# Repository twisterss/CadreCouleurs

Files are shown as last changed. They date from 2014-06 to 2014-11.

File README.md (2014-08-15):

# Decorative LED frame

## More info

Find details about the way to [build the frame yourself here](http://www.viesurip.fr/en/2014/06/17/un-cadre-en-couleurs/).

## Repository structure

  * The "cadre" directory contains the Arduino sketch to control the display;
  * The "elec" directory contains the schematic of the control part of the frame;
  * The "things" directory contains the models to 3D-print or laser-cut to modify the frame;
  * The "tools" directory contains various tools useful to modify the frame.

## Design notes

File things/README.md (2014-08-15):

# 3D parts for the frame

OpenSCAD has been used to build the 3D models.

## The box

It contains the electronics of the frame. It can easily by 3D-printed in two parts.

## The grid

It separates the LEDs. It can be either 3D-printed (STL files) or laser-cut (SVG file produced using Python).

It is better to print it in one part, but it can be printed in two parts.

## The holder

It is used to keep the grid inside the frame.

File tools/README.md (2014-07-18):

# Tools for the frame

* colors.py script to generate a list of colors to load on the Arduino
* Color loader sketch to fill the EEPROM memory with color values
* font spreadsheet to design characters to display on the frame

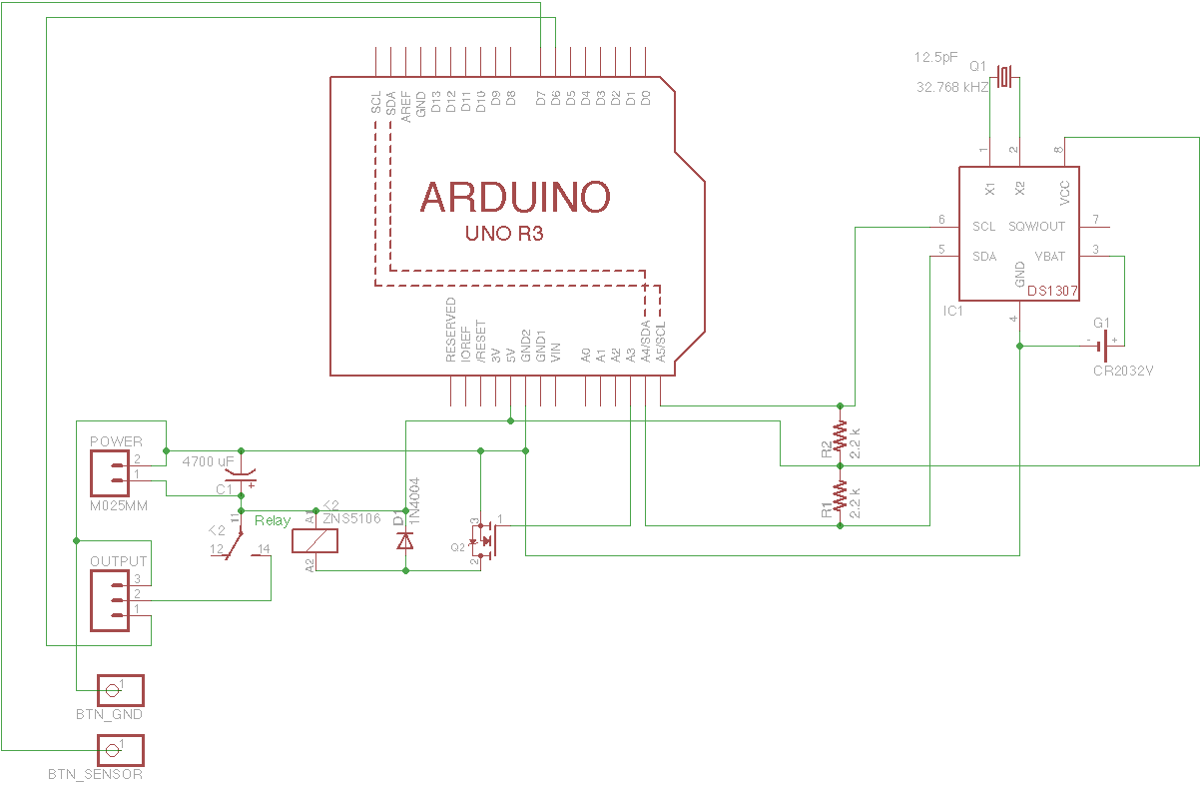
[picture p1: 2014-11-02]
elec/control-circuit.png

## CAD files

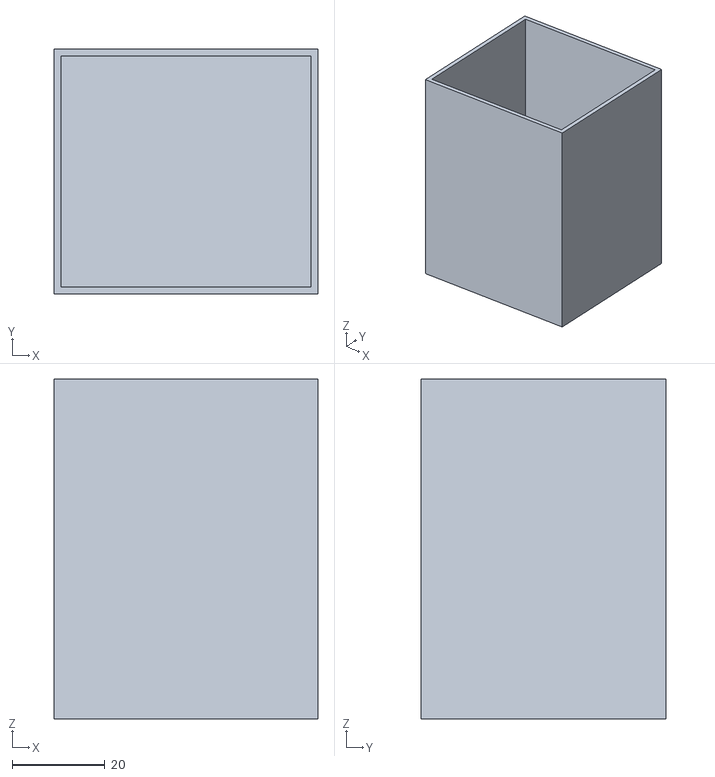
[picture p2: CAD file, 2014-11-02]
things/box_full.stl
57.0 x 53.0 x 73.5

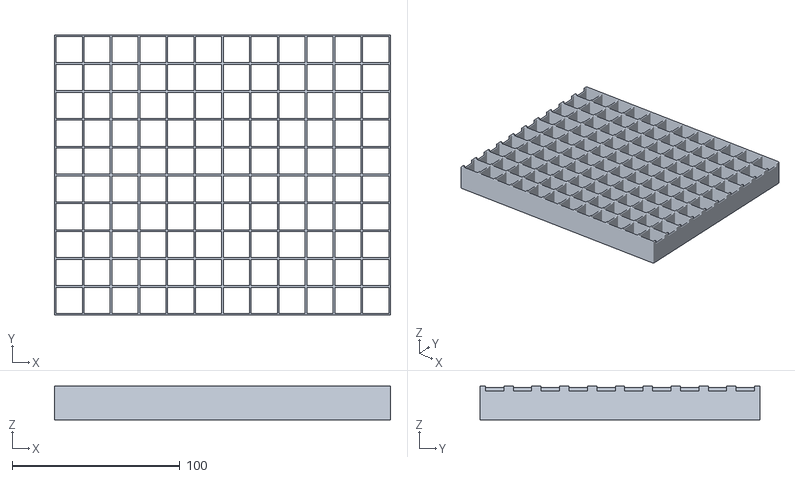
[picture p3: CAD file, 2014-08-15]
things/full_grid.stl
200.2 x 167.0 x 20.0

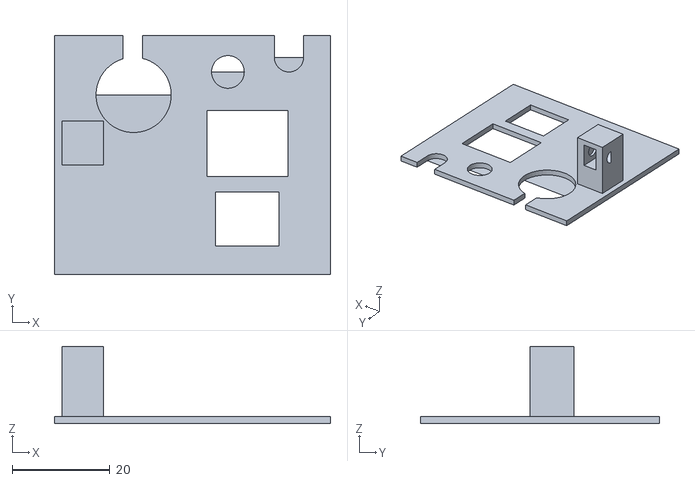
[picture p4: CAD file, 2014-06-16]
things/box_end.stl
56.5 x 49.0 x 15.8

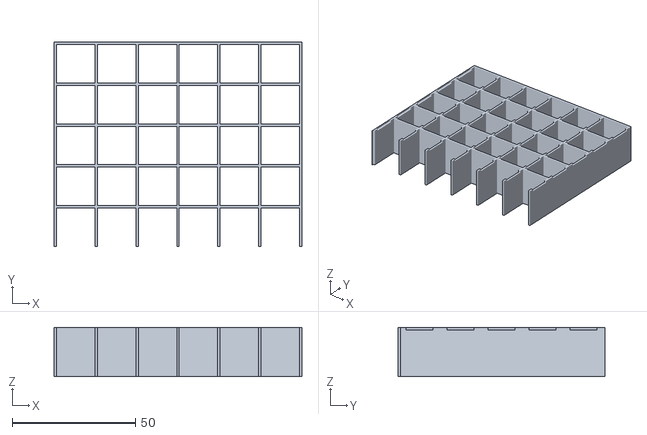
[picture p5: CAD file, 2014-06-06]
things/grid_y.stl
100.6 x 84.0 x 20.0

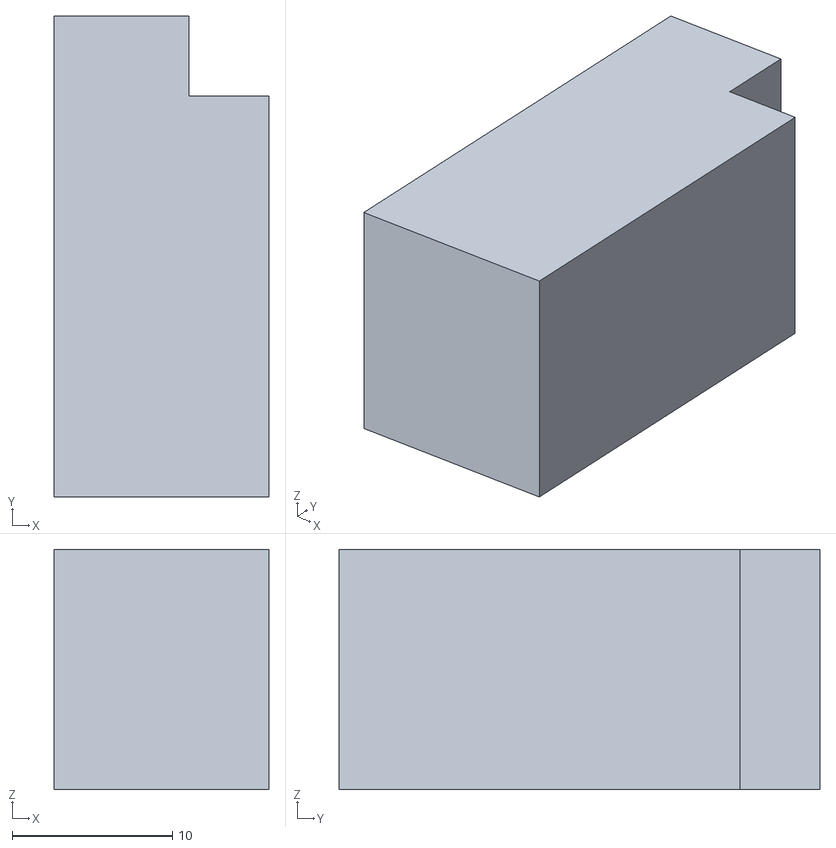
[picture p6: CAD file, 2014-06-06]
things/holder.stl
13.4 x 30.0 x 15.0

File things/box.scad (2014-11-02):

$fn = 50;

content_width = 54;
content_depth = 72;
content_height = 50;
wall = 1.5;
screw_sep = 5;
screw_bottom = 21;
screw_diam = 3.5;
screw_width = 6.3;
screw_height = 7.5;
screw_depth = 4;

module box() {
	difference() {
		cube([content_width + wall*2, content_depth + wall, content_height + wall * 2]);
		translate([wall, wall, wall]) {
			cube([content_width, content_depth, content_height]);
		}
	}
}

module end() {
	translate([0, content_depth + wall, 0]) {
		union() {
			difference() {
				cube([content_width + wall * 2, wall, content_height + wall * 2]);
				translate([wall, 0, wall]) {
					// Power hole
					translate([content_width-10, 0, content_height - 3])
						cube([6, wall, 3 + wall]);
					translate([content_width-7, wall, content_height - 3])
						rotate([90, 0, 0])
							cylinder(h = wall+1, r = 3);
					// USB hole
					translate([31.5, 0, 4.4])
						cube([13, wall, 11]);
					// Ethernet hole
					translate([29.75, 0, 18.6])
						cube([16.5, wall, 13.5]);
					// Output plug hole
					translate([12.5, 0, content_height + wall - 6])
						cube([4, wall, 6]);
					translate([14.7, wall, content_height - 10.7])
						rotate([90, 0, 0])
							cylinder(h = wall+1, r = 7.7);
					// Button hole
					translate([34, wall, content_height - 6])
						rotate([90, 0, 0])
							cylinder(h = wall+1, r = 3.35);
				}
			}
			// Holding part 1
			translate([wall, -(screw_sep + screw_width + wall*2), screw_bottom + wall]) {
				difference() {
					cube([wall*3 + screw_depth, screw_sep + screw_width + wall*2, screw_height + wall]);
					translate([wall*1.5, wall, wall])
						cube([screw_depth, screw_width, screw_height]);
					translate([0, screw_width/2 + wall, screw_height/2 + wall])
						rotate([0, 90, 0])
							cylinder(h = wall*3 + screw_depth, r = screw_diam/2);
				}
			}
		}
	}
}

box();
end();

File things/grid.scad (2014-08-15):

// Grid to separate pixels on the frame.
// Can be 3D-printed in 1 or 4 parts.
// See different combinations at the end of the file

// Basic dimensions
pixel_width = 16.6;
pixel_wall = 1;
pixel_height = 20;
strip_width = 11;
strip_height = 0.8;
strip_big_height = 2.8;

// Grid drawing module
// pixels_x, pixels_y: Grid size
// remove_wall_x, remove_wall_x: Leave space to put another grid side by side
// bigger_strip_start, bigger_strip_end: Leave space for soldering on the end
module grid(pixels_x, pixels_y, remove_wall_x, remove_wall_y, bigger_strip_start, bigger_strip_end) {
	difference() {
		union() {
			for (x = [0 : pixels_x]) {
				translate([x * pixel_width, 0, 0])
					cube([pixel_wall, pixels_y * pixel_width + pixel_wall, pixel_height]);
			}
			for (y = [0 : pixels_y]) {
				translate([0, y * pixel_width, 0])
					cube([pixels_x * pixel_width + pixel_wall, pixel_wall, pixel_height]);
			}
		}
		for (y = [0 : pixels_y-1]) {
			translate([0, (pixel_width + pixel_wall - strip_width)/2 + y * pixel_width, 0]) {
				cube([pixels_x * pixel_width + pixel_wall, strip_width, strip_height]);
				if (bigger_strip_start)
					cube([pixel_wall, strip_width, strip_big_height]);
				if (bigger_strip_end)
					translate([pixels_x * pixel_width, 0, 0])
						cube([pixel_wall, strip_width, strip_big_height]);
			}
		}
		if (remove_wall_x)
			cube([pixel_wall, pixels_y * pixel_width + pixel_wall, pixel_height]);
		if (remove_wall_y)
			cube([pixels_x * pixel_width + pixel_wall, pixel_wall, pixel_height]);
	}
}

// Full grid made of one part
grid(12, 10, 0, 0, 1, 1);

// Grid made of 4 parts for smaller printers (print both twice)
//grid(6, 5, 1, 0, 0, 0);
//translate([6*pixel_width+5, 0, 0])
//	grid(6, 5, 0, 1, 0, 0);

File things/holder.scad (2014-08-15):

// Holder to prevent the grid from moving inside the frame
// For the laser-cut grid, use holder=0

// Actual inside width of the frame
frame_width = 217;

// Size of the grid
pixel_width = 16.6;
pixel_wall = 1;
pixel_height = 20;

pixels_x = 12;
pixels_y = 10;

// Size of the protruding parts holding the grid
holder = 5;

difference() {
	cube([(frame_width - pixel_width * pixels_x - pixel_wall) / 2 + holder, (frame_width - pixel_width * pixels_y - pixel_wall) / 2 + holder, pixel_height-5]);
	translate([(frame_width - pixel_width * pixels_x - pixel_wall) / 2, (frame_width - pixel_width * pixels_y - pixel_wall) / 2, 0])
		cube([holder+1, holder+1, pixel_height-5]);
}

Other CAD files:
things/grid_x.stl

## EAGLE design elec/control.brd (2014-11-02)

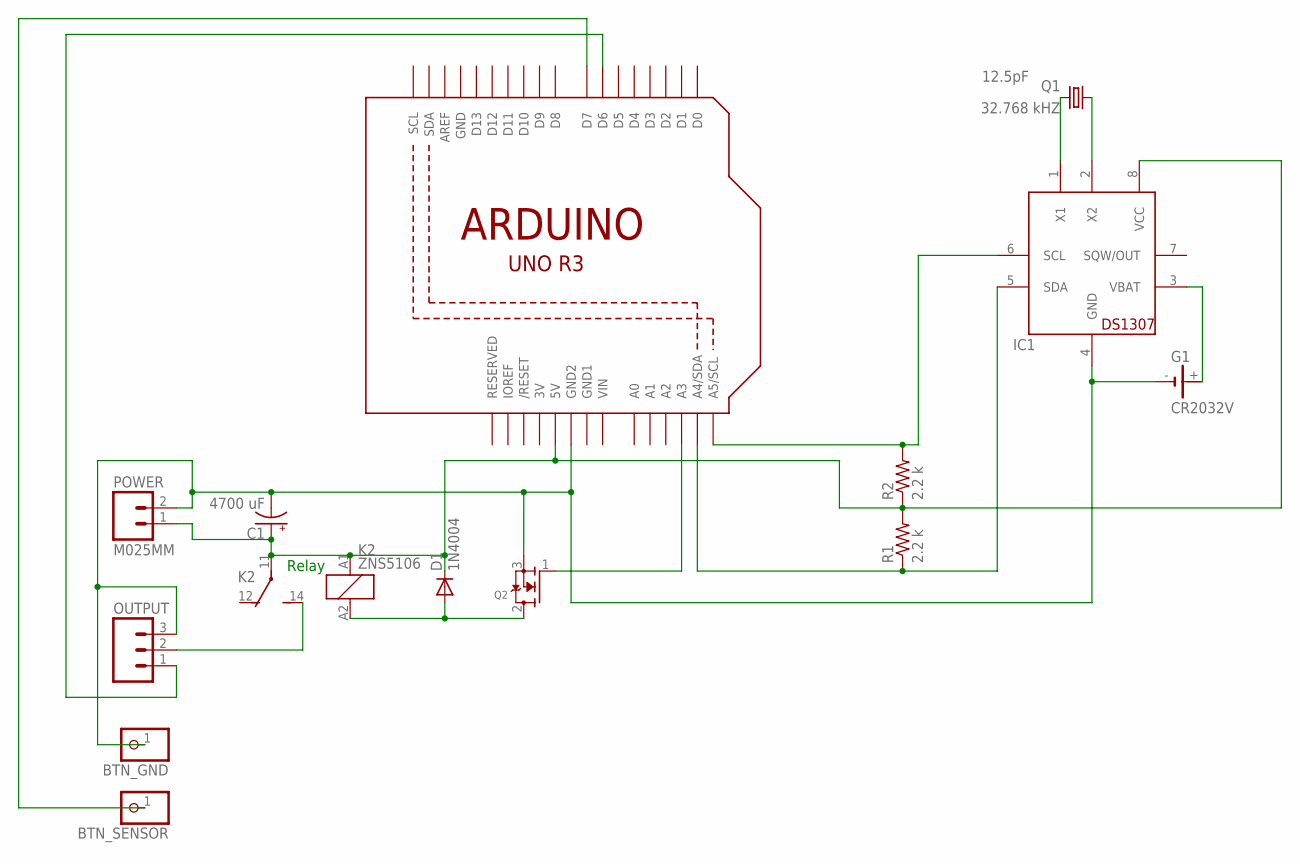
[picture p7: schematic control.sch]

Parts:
BTN_GND: PINHD-1X1CB; 1X01-CLEANBIG
BTN_SENSOR: PINHD-1X1CB; 1X01-CLEANBIG
C1: 4700 uF; E5-10,5
D1: 1N4004; DO41-10
G1: CR2032V
IC1: DS1307; DIL08
K2: ZNS5106; ZN5
OUTPUT: M03-SCREW-5MM; SCREWTERMINAL-5MM-3
POWER: M025MM; SCREWTERMINAL-5MM-2
Q1: 32.768 kHZ; TC38H
Q2: MOSFET-NGDS_TO220V; TO220V
R1, R2: 2.2 k; 0207/10
U1: ARDUINOR3-BPLACE

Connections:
3V: U1.3V
GND: U1.GND
GND1: U1.GND1
unnamed: BTN_GND.1, C1.-, G1.-, IC1.4 (GND), OUTPUT.3, POWER.2, Q2.3 (S), U1.GND2
unnamed: IC1.1 (X1), Q1.2
unnamed: Q2.1 (G), U1.A3
unnamed: D1.A, K2.A2 (2), Q2.2 (D)
unnamed: K2.14 (S), OUTPUT.2
unnamed: OUTPUT.1, U1.D6
unnamed: BTN_SENSOR.1, U1.D7
unnamed: IC1.2 (X2), Q1.1
unnamed: G1.+, IC1.3 (VBAT)
unnamed: IC1.6 (SCL), R2.2, U1.A5 (A5/SCL)
unnamed: IC1.5 (SDA), R1.1, U1.A4 (A4/SDA)
unnamed: C1.+, D1.C, IC1.8 (VCC), K2.11, K2.A1 (1), POWER.1, R1.2, R2.1, U1.5V
VIN: U1.VIN

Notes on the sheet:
Relay

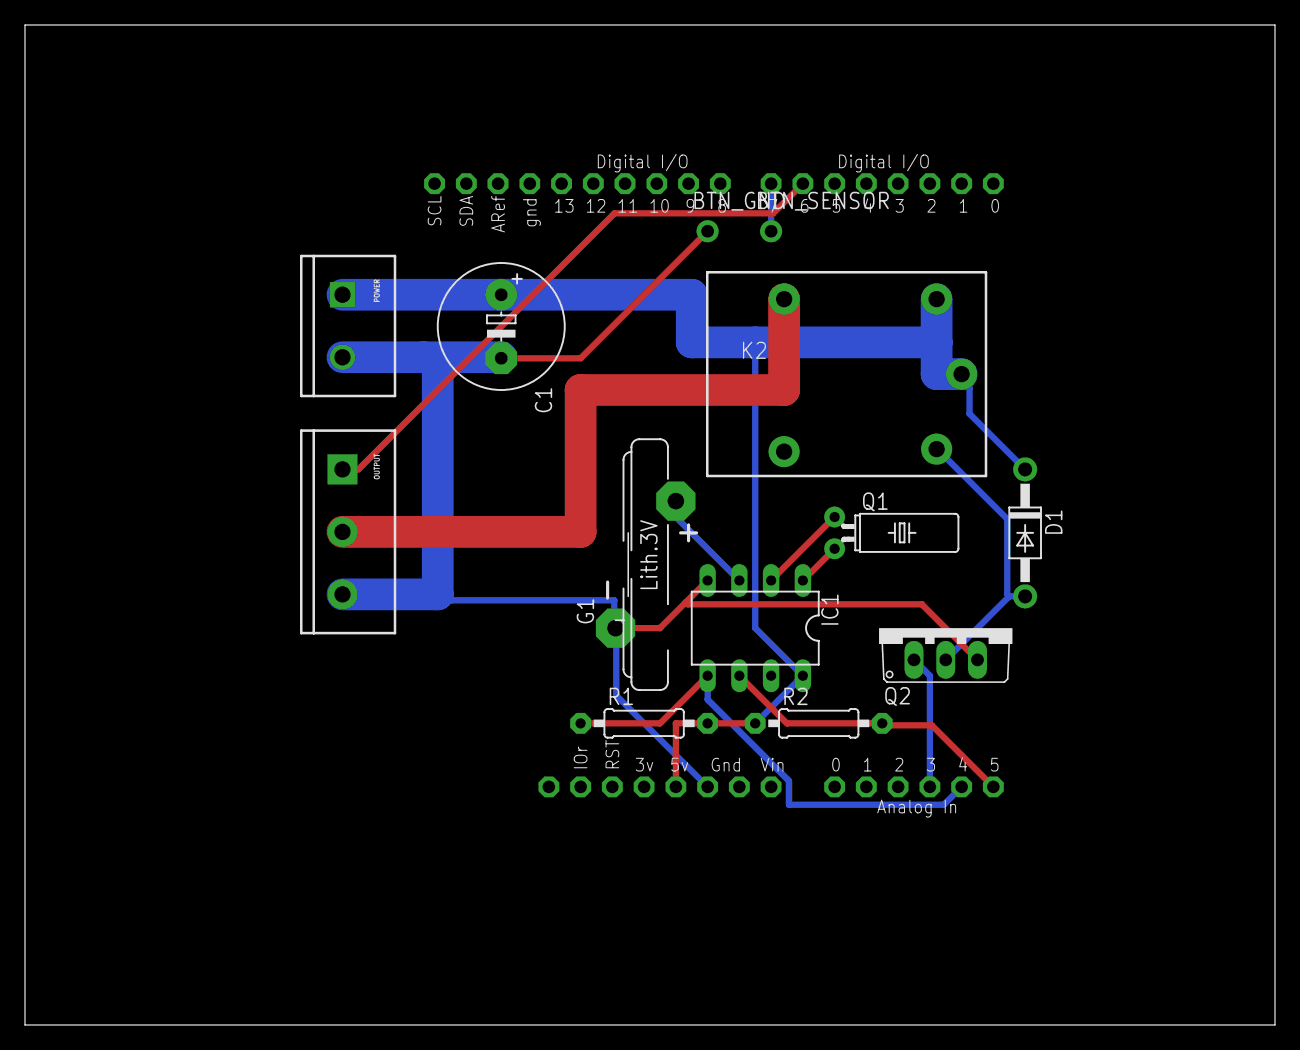
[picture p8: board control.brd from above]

Board: 2 copper layers, 100.0 x 80.0 mm, 14 parts (0 on the bottom side), 12 nets.

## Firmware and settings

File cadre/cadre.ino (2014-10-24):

// This is the main sketch of the color frame.
// It contains a control web server and the display control.
// Think of loading colors in the EEPROM before using this sketch.

#include <avr/wdt.h>
#include <SPI.h>
#include <Ethernet.h>
#include <Wire.h>  
#include "RTCControl.h"
#include <Time.h> 
#include <Adafruit_NeoPixel.h>
#include "Pixels.h"
#include "WebServer.h"
#include <EEPROM.h>

// Hardware configuration
#define STRIP_PIN_DATA 6
#define STRIP_PIN_POWER A3
#define BUTTON_PIN 7

// Minimum delay between two display states (microseconds)
#define DISPLAY_DELAY 1000
// Maximum number of characters for a displayed message
#define MAX_TEXT_SIZE 30

// Number of colors stored in EEPROM
#define COLOR_HUES 85
#define COLOR_SATS 4

// Working modes
#define MODE_OFF 0
#define MODE_CLOCK 1
#define MODE_COLOR 2
#define MODE_GRADIENT 3
#define MODE_RANDOM 4
#define MODE_TEXT 5
#define MODE_DEMO 6
#define MODE_RAINBOW 8
#define MODE_ADDRESS 255

// MAC address of the server
byte mac[] = {
  0x90, 0xA2, 0xDA, 0x00, 0xEA, 0xF8
};

// Letters to display (5x5)
const byte letters[][5] = {
  {0x7c,0x44,0x44,0x7c,0x44}, // A
  {0x7c,0x44,0x78,0x44,0x7c},  
  {0x7c,0x40,0x40,0x40,0x7c},  
  {0x78,0x44,0x44,0x44,0x78},  
  {0x7c,0x40,0x78,0x40,0x7c},
  {0x7c,0x40,0x70,0x40,0x40},
  {0x7c,0x40,0x4c,0x44,0x7c},
  {0x44,0x44,0x7c,0x44,0x44},
  {0x7c,0x10,0x10,0x10,0x7c},
  {0x0c,0x04,0x04,0x44,0x7c},
  {0x44,0x48,0x70,0x48,0x44},
  {0x40,0x40,0x40,0x40,0x7c},
  {0x44,0x6c,0x54,0x44,0x44},
  {0x44,0x64,0x54,0x4c,0x44},
  {0x38,0x44,0x44,0x44,0x38},  
  {0x78,0x44,0x78,0x40,0x40},              
  {0x7c,0x44,0x44,0x7c,0x10},            
  {0x78,0x44,0x78,0x44,0x44},            
  {0x7c,0x40,0x7c,0x04,0x7c},            
  {0x7c,0x10,0x10,0x10,0x10},              
  {0x44,0x44,0x44,0x44,0x7c},            
  {0x44,0x44,0x28,0x28,0x10},            
  {0x44,0x44,0x54,0x54,0x28},            
  {0x44,0x28,0x10,0x28,0x44},            
  {0x44,0x44,0x28,0x10,0x10},            
  {0x7c,0x08,0x10,0x20,0x7c}, // Z
  {0x38,0x4C,0x54,0x64,0x38}, // 0
  {0x70,0x10,0x10,0x10,0x7C},
  {0x7C,0x04,0x7C,0x40,0x7C},
  {0x7C,0x04,0x1C,0x04,0x7C},
  {0x40,0x48,0x7C,0x08,0x08},
  {0x7C,0x40,0x7C,0x04,0x7C},
  {0x7C,0x40,0x7C,0x44,0x7C},
  {0x78,0x08,0x1C,0x08,0x08},
  {0x38,0x44,0x38,0x44,0x38},
  {0x7C,0x44,0x7C,0x04,0x7C}, // 9  
  {0x00,0x00,0x00,0x00,0x00}, // space
  {0x00,0x00,0x00,0x30,0x30}, // dot
  {0x28,0x7C,0x7C,0x38,0x10}, // heart
  {0x00,0x28,0x00,0x44,0x38}, // happy smiley
  {0x00,0x28,0x00,0x38,0x44}  // unhappy smiley
};

// Web server
WebServer server(80);
// LED strip
Pixels pixels(STRIP_PIN_DATA, STRIP_PIN_POWER);

// Display state
unsigned long lastDisplayEvent = 0;
bool newOrderReceived = true;
bool newOrderInternal = false;

// Current configuration (used by all modes)
typedef struct State {
  uint8_t mode;
  uint32_t color1;
  uint32_t color2;
  char text[MAX_TEXT_SIZE];
  uint8_t speed;
  uint8_t brightness;
} State;
State current;

/**
 * Load the current state from RTC RAM
 */
void loadCurrent() {
  RTC.readBytesInRam(0, sizeof(current), (uint8_t*) &current);
}

/**
 * Save the current state in RTC RAM
 */
void saveCurrent() {
  RTC.writeBytesInRam(0, sizeof(current), (uint8_t*) &current);
}

/**
 * Mix 2 colors together.
 * If step = 0, this is color1, if step = maxStep, this is color2, between, this is a mix
 */
uint32_t transitionColor(uint8_t step, uint8_t maxStep, uint32_t color1, uint32_t color2 = 0) {
  uint16_t r1, g1, b1, r2, g2, b2;
  r1 = (uint8_t) (color1 >> 16); g1 = (uint8_t) (color1 >> 8); b1 = (uint8_t) color1; 
  r2 = (uint8_t) (color2 >> 16); g2 = (uint8_t) (color2 >> 8); b2 = (uint8_t) color2; 
  r1 *= maxStep - step; g1*= maxStep - step; b1 *= maxStep - step;
  r2 *= step; g2*= step; b2 *= step;
  r1+= r2; g1+= g2; b1+= b2;
  r1/= maxStep; g1/= maxStep; b1/= maxStep; 
  return pixels.color(r1, g1, b1);
}

/**
 * Load a color value from EEPROM
 * depending on discrete hue and saturation values.
 * Brightness is computed and can be any value from 0 to 255.
 */
uint32_t loadColor(uint8_t hue, uint8_t bright = 255, uint8_t sat = COLOR_SATS-1) {
  uint16_t colorInd = (hue * COLOR_SATS + sat) * 3;
  return transitionColor(255-bright, 255, pixels.color(EEPROM.read(colorInd), EEPROM.read(colorInd + 1), EEPROM.read(colorInd + 2)));
}

/**
 * Return a random color with a minimum hue
 * distance from the last random color.
 * The saturation and brightness ranges can be changed.
 */
uint32_t randomColor(uint8_t minDist = 0, uint8_t minBright = 0, uint8_t maxBright = 255, uint8_t minSat = 0, uint8_t maxSat = COLOR_SATS-1) {
  static uint8_t oldHue = 0;
  uint8_t hue, sat, bright;
  uint16_t topBright;
  do {
    // Choose a color
    hue = random(COLOR_HUES);
  } while (!((hue <= oldHue && (oldHue - hue) >= minDist && (hue + COLOR_HUES - oldHue) >= minDist) ||
    (hue > oldHue && (hue - oldHue >= minDist) && (oldHue + COLOR_HUES - hue) >= minDist)));
  oldHue = hue;
  topBright = maxBright;
  topBright+=1;
  bright = random(minBright, topBright);
  sat = random(minSat, maxSat+1);
  return loadColor(hue, bright, sat);
}

/**
 * Print a fixed text on the display
 */
void fixedText(const char* string, uint32_t color, int16_t startX = 0, int16_t startY = 2) {
  uint16_t length = strlen(string);
  uint16_t letterIndex = 0;
  uint8_t letter = 0;
  uint8_t column = 0;
  for (int16_t x = startX; x < pixels.width(); x++) {
    if (column == 0) {
      // Select the letter
      // Finished writing the text?
      if (letterIndex >= length)
        return;
      letter = string[letterIndex];
      // Convert ASCII to table index
      if (letter >= 65 && letter <= 90)
        letter-= 65; // upper case
      else if (letter >= 97 && letter <= 122)
        letter-= 97; // lower case
      else if (letter >= 48 && letter <= 57)
        letter-= 22; // numbers
      else if (letter == 46)
        letter = 37; // dot
      else if (letter == 60)
        letter = 38; // heart
      else if (letter == 41)
        letter = 39; // happy smiley
      else if (letter == 40)
        letter = 40; // unhappy smiley
      else
        letter = 36; // space
      letterIndex++;
    }
    for (int16_t y = startY; y < pixels.height() && y < startY + 5; y++) {
      if (x >= 0 && x < pixels.width() && y >= 0 && y < pixels.height() && (letters[letter][y - startY] >> (6 - column)) & 1)
        pixels.set(x, y, color);
    }
    column++;
    if (column >= 6)
      column = 0;
  }
}


/**
 * Print the current time on the display
 */
void fixedTime(uint32_t hoursColor, uint32_t minutesColor, uint32_t backgroundColor = 0) {
    pixels.clear(backgroundColor);
    char tmpChars[3];
    String tmpString;
    tmpString = String(hour());
    if (tmpString.length() < 2)
      tmpString = "0" + tmpString;
    tmpString.toCharArray(tmpChars, 3);
    fixedText(tmpChars, hoursColor, 0, 0);
    tmpString = String(minute());
    if (tmpString.length() < 2)
      tmpString = "0" + tmpString;
    tmpString.toCharArray(tmpChars, 3);
    fixedText(tmpChars, minutesColor, 1, 5);
}

/**
 * Utility to so sometheing every n steps.
 * Returns true every n steps
 */
bool skipSteps(uint16_t steps) {
  static uint16_t step = 0;
  step++;
  if (step >= steps) {
    step = 0;
    return true;
  }
  return false;
}

/**
 * Display the IP address of the frame once
 */
void displayAddress(bool newDisplay) {
  if (newDisplay) {
    String address = String(server.localIP()[0]) + "." + String(server.localIP()[1]) + "." + String(server.localIP()[2]) + "." + String(server.localIP()[3]);
    address.toCharArray(current.text, MAX_TEXT_SIZE);
    current.color1 = pixels.color(255, 255, 255);
    current.color2 = pixels.color(0, 0, 0);
  }
  if (displayText(newDisplay)) {
    // IP displayed: back to last mode
    newOrderInternal = true;
    loadCurrent();
  }
}

/**
 * Display nothing
 */
void displayOff(bool newDisplay) {
  if (newDisplay) {
    pixels.switchOff();
  }
}

/**
 * Display the time
 */
void displayClock(bool newDisplay) {
  if (newDisplay || skipSteps(1000)) {
    fixedTime(current.color1, current.color2);
    pixels.commit();
  }
}

/**
 * Display a constant color on the frame
 */
void displayConstantColor(bool newDisplay) {
  static int y = 0;
  if (newDisplay)
    y = 0;
  if (skipSteps(50)) {
    if (y < pixels.height()) {
      for (uint8_t x = 0; x < pixels.width(); x++)
          pixels.set(x, y, current.color1);
      pixels.commit();
      y++;
    }
  }
}

/**
 * Display random continually changing colors
 */
void displayGradient(bool newDisplay) {
  static uint32_t color;
  static uint8_t remaining = 0;
  if (newDisplay || remaining == 0) {
    // Select a color
    color = randomColor(15, current.brightness, current.brightness, 2);
    // Count the number of pixels to change
    remaining = 0;
    for (uint8_t x = 0; x < pixels.width(); x++)
      for (uint8_t y = 0; y < pixels.height(); y++)
        if (pixels.get(x, y) != color)
          remaining++;
  }
  if (skipSteps(300)) {
    // Find a pixel to change
    uint8_t toChange = random(remaining);
    bool done  = false;
    for (uint8_t x = 0; x < pixels.width() && !done; x++) {
      for (uint8_t y = 0; y < pixels.height() && !done; y++) {
        if (pixels.get(x, y) != color) {
          if (toChange == 0) {
            pixels.set(x, y, color);
            done = true;
          }
          toChange--;
        }
      }
    }
    pixels.commit();
    remaining--;
  }
}

/**
 * Display some geometric shapes
 */
void displayRandom(bool newDisplay) {
  if (skipSteps(5)) {
    pixels.set(random(pixels.width()), random(pixels.height()), randomColor(1, min(50, current.brightness), current.brightness));
    pixels.commit();
  }
}

/**
 * Display a sliding text.
 * Returns if it is an end of text
 */
bool displayText(bool newDisplay) {
  static uint16_t columns = 0;
  static uint16_t column = 0;
  if (newDisplay || column == columns) {
    columns = strlen(current.text) * 6 + pixels.width();
    column = 0;
  }
  if (skipSteps(100)) {
    pixels.clear(current.color2);
    fixedText(current.text, current.color1, pixels.width() - 1 - column);
    pixels.commit();
    column++;
  }
  return column == columns;
}

/**
 * Display a bit of everything for a demo
 */
void displayDemo(bool newDisplay) {
  static uint8_t mode;
  static uint16_t duration;
  bool newMode = false;
  if (newDisplay) {
    mode = MODE_RANDOM;
    duration = 0;
    newMode = true;
  }
  if (duration >= 10000) {
    // Change the mode
    if (mode == MODE_RANDOM) {
      mode = MODE_TEXT;
      current.color1 = pixels.color(current.brightness, current.brightness, current.brightness);
      current.color2 = pixels.color(0, 0, 0);
    } else if (mode == MODE_TEXT) {
      current.speed = 255;
      mode = MODE_RAINBOW;
    } else if (mode == MODE_RAINBOW) {
      mode = MODE_CLOCK;
      current.color1 = transitionColor(255-current.brightness, 255, pixels.color(255, 0, 0));
      current.color2 = transitionColor(255-current.brightness, 255, pixels.color(180, 180, 0));
    } else {
      mode = MODE_RANDOM;
    }
    newMode = true;
    duration = 0;
  }
  switch(mode) {
    case MODE_CLOCK:
      displayClock(newMode);
      break;
    case MODE_RAINBOW:
      displayRainbow(newMode);
      break;
    case MODE_RANDOM:
      displayRandom(newMode);
      break;
    case MODE_TEXT:
      displayText(newMode);
      break;
  }
  duration++;
}


/**
 * Display a rainbow
 */
void displayRainbow(bool newDisplay) {
  static uint8_t colorInd = 0, trans = 0, transMax;
  uint32_t color;
  int8_t diag, x, y;
  if (newDisplay) {
    // Set the speed by changing the number of transitions
    uint8_t newTransMax = 90 - (current.speed / 3);
    trans = (trans * newTransMax) / transMax;
    transMax = newTransMax;
  }
  if (skipSteps(20)) {
    // Update pixels by the diagonal
    for (diag = 0; diag <= pixels.width() + pixels.height() - 2; diag++) {
      color = transitionColor(trans, transMax, loadColor((colorInd + (diag)*2) % COLOR_HUES, current.brightness), loadColor((colorInd + (diag+1)*2) % COLOR_HUES, current.brightness));
      if (diag >= pixels.height()) {
        y = pixels.height() - 1;
        x = diag - y;
      } else {
        x = 0;
        y = diag;
      }
      while(x < pixels.width() && y >= 0) {
        pixels.set(x, y, color);
        x+= 1;
        y-= 1;
      }
    }
    // Get ready for next step
    trans++;
    if (trans >= transMax) {
      trans = 0;
      colorInd+=2;
      if (colorInd >= COLOR_HUES)
        colorInd = 0;
    }
    pixels.commit();
  }
}
  

/**
 * Manage one generic display step
 */
void display() {
  switch(current.mode) {
    case MODE_OFF:
      displayOff(newOrderReceived);
      break;
    case MODE_CLOCK:
      displayClock(newOrderReceived);
      break;
    case MODE_COLOR:
      displayConstantColor(newOrderReceived);
      break;
    case MODE_GRADIENT:
      displayGradient(newOrderReceived);
      break;
    case MODE_RANDOM:
      displayRandom(newOrderReceived);
      break;
    case MODE_TEXT:
      displayText(newOrderReceived);
      break;
    case MODE_DEMO:
      displayDemo(newOrderReceived);
      break;
    case MODE_RAINBOW:
      displayRainbow(newOrderReceived);
      break;
    case MODE_ADDRESS:
      displayAddress(newOrderReceived);
      break;
  }
  newOrderReceived = newOrderInternal;
  newOrderInternal = false;
}

/**
 * Dynamic response to server requests
 */
WebResponse listenToRequests(WebRequest &request) {
  if (request.resource == "setMode") {
    // Received a request to change the current mode
    uint8_t offset = 0;
    // Decode url-encoding
    request.params.replace("%20", " ");
    request.params.replace("%3C", "<");
    // Get the mode
    current.mode = request.params.substring(offset, offset+2).toInt();
    offset+= 2;
    // Get the settings
    if (current.mode == MODE_CLOCK || current.mode == MODE_COLOR || current.mode == MODE_TEXT) {
      current.color1 = pixels.color(request.params.substring(offset, offset+3).toInt(), request.params.substring(offset+3, offset+6).toInt(), request.params.substring(offset+6, offset+9).toInt());
      offset+= 9;
    }
    if (current.mode == MODE_CLOCK || current.mode == MODE_TEXT) {
      current.color2 = pixels.color(request.params.substring(offset, offset+3).toInt(), request.params.substring(offset+3, offset+6).toInt(), request.params.substring(offset+6, offset+9).toInt());
      offset+= 9;
    }
    if (current.mode == MODE_RAINBOW) {
      current.speed = request.params.substring(offset, offset+3).toInt();
      offset+=3;
    }
    if (current.mode == MODE_RAINBOW || current.mode == MODE_RANDOM || current.mode == MODE_GRADIENT || current.mode == MODE_DEMO) {
      current.brightness = request.params.substring(offset, offset+3).toInt();
      offset+=3;
    }
    if (current.mode == MODE_CLOCK) {
      // Set the current time
      time_t time = request.params.substring(offset).toInt();
      RTC.set(time);
      setTime(time);
    }
    if (current.mode == MODE_TEXT || current.mode == MODE_DEMO) {
      request.params.substring(offset).toCharArray(current.text, MAX_TEXT_SIZE);
    }
    // Save the state in RTC RAM
    saveCurrent();
    newOrderReceived = true;
    // Send an OK response
    WebResponse response = WebResponse::createText("OK");
    response.setAllowAllOrigins();
    return response;
  }
  return WebResponse::createNull();
}

/**
 * Check the current state of the button.
 * Used to display the IP address
 */
void checkButton() {
  if (digitalRead(BUTTON_PIN) == LOW && current.mode != MODE_ADDRESS && server.isConnected()) {
    current.mode = MODE_ADDRESS;
    newOrderReceived = true;
  }
}

/**
 * Initialization procedure
 */
void setup() {
  // Pins initialization
  pinMode(BUTTON_PIN, INPUT_PULLUP);
  // Pixels initialization
  pixels.begin();
  // Random generator initialization
  randomSeed(analogRead(0));
  // Time (RTC clock) initialization
  setSyncProvider(RTC.get);
  // Network initialization (skiped if the button is pushed)
  if (digitalRead(BUTTON_PIN) == HIGH) {
    server.registerServeMethod(listenToRequests);
    // Keep trying to connect
    do {
      server.begin(mac);
    } while (!server.isConnected());
    // Connection done: load last mode from memory
    loadCurrent();
  } else {
    // No connection: demo mode
    current.mode = MODE_DEMO;
    current.brightness = 255;
    strcpy(current.text, "Cadre couleurs");
  }
  // Watchdog initialization, only after long network intialization
  wdt_enable(WDTO_4S);
}

/**
 * Main ever-running procedure
 */
void loop() {
  // Serve one HTTP request if any
  server.serve();
  // Check the button
  checkButton();
  // Display periodically
  static unsigned long lastDisplayEvent = 0;
  const unsigned long timeNow = micros();
  const unsigned long duration = timeNow - lastDisplayEvent;
  if (duration >= DISPLAY_DELAY) {
    display();
    lastDisplayEvent = timeNow;
    // Tell the watchdog the program is running properly
    wdt_reset();
  }
}

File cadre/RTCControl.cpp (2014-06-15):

#include <Wire.h>
#include "RTCControl.h"

#define DS1307_CTRL_ID 0x68 

RTCControl::RTCControl()
{
  Wire.begin();
}
  
// PUBLIC FUNCTIONS
time_t RTCControl::get()   // Aquire data from buffer and convert to time_t
{
  tmElements_t tm;
  if (read(tm) == false) return 0;
  return(makeTime(tm));
}

bool RTCControl::set(time_t t)
{
  tmElements_t tm;
  breakTime(t, tm);
  tm.Second |= 0x80;  // stop the clock 
  write(tm); 
  tm.Second &= 0x7f;  // start the clock
  write(tm); 
}

// Aquire data from the RTC chip in BCD format
bool RTCControl::read(tmElements_t &tm)
{
  uint8_t sec;
  Wire.beginTransmission(DS1307_CTRL_ID);
  Wire.write((uint8_t)0x00); 
  if (Wire.endTransmission() != 0) {
    exists = false;
    return false;
  }
  exists = true;

  // request the 7 data fields   (secs, min, hr, dow, date, mth, yr)
  Wire.requestFrom(DS1307_CTRL_ID, tmNbrFields);
  if (Wire.available() < tmNbrFields) return false;
  sec = Wire.read();
  tm.Second = bcd2dec(sec & 0x7f);   
  tm.Minute = bcd2dec(Wire.read() );
  tm.Hour =   bcd2dec(Wire.read() & 0x3f);  // mask assumes 24hr clock
  tm.Wday = bcd2dec(Wire.read() );
  tm.Day = bcd2dec(Wire.read() );
  tm.Month = bcd2dec(Wire.read() );
  tm.Year = y2kYearToTm((bcd2dec(Wire.read())));
  if (sec & 0x80) return false; // clock is halted
  return true;
}

bool RTCControl::write(tmElements_t &tm)
{
  Wire.beginTransmission(DS1307_CTRL_ID);
  Wire.write((uint8_t)0x00); // reset register pointer  
  Wire.write(dec2bcd(tm.Second)) ;   
  Wire.write(dec2bcd(tm.Minute));
  Wire.write(dec2bcd(tm.Hour));      // sets 24 hour format
  Wire.write(dec2bcd(tm.Wday));   
  Wire.write(dec2bcd(tm.Day));
  Wire.write(dec2bcd(tm.Month));
  Wire.write(dec2bcd(tmYearToY2k(tm.Year))); 
  if (Wire.endTransmission() != 0) {
    exists = false;
    return false;
  }
  exists = true;
  return true;
}

void RTCControl::readBytesInRam(uint8_t address, uint8_t length, uint8_t* p_data) {
    Wire.beginTransmission(DS1307_CTRL_ID);
    Wire.write(address+8);    
    Wire.endTransmission();
 
    Wire.requestFrom(DS1307_CTRL_ID, (int)length);
    for (uint8_t i = 0; i < length; i++) {
        p_data[i] = Wire.read();
    }
    Wire.endTransmission();
}

void RTCControl::writeBytesInRam(uint8_t address, uint8_t length, uint8_t* p_data) {
    Wire.beginTransmission(DS1307_CTRL_ID);
    Wire.write(address+8);    
    for (uint8_t i = 0; i < length; i++) {
        Wire.write(p_data[i]);
    }
    Wire.endTransmission();
}

// PRIVATE FUNCTIONS

// Convert Decimal to Binary Coded Decimal (BCD)
uint8_t RTCControl::dec2bcd(uint8_t num)
{
  return ((num/10 * 16) + (num % 10));
}

// Convert Binary Coded Decimal (BCD) to Decimal
uint8_t RTCControl::bcd2dec(uint8_t num)
{
  return ((num/16 * 10) + (num % 16));
}

bool RTCControl::exists = false;

RTCControl RTC = RTCControl(); // create an instance for the user

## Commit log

2014-06-06 Initial commit
    The code works. First version with basic features.
    [box.scad, box_end.stl, box_full.stl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]
2014-06-07 Made random mode default
    Skipped showing the IP address if not connected.
    [cadre.ino]
2014-06-09 Added a watchdog and cleaned up
    Distance calculation for colors is a bit better.
    IP address display time is as short as possible.
    Removed useless features in Pixels.
    [Pixels.cpp, cadre.ino]
2014-06-16 Added a button to display the IP address
    Also added the possibility to skip network connection when booting with
    button pressed.
    The box containing the Arduino has been modified to include the new
    plug and button.
    [box.scad, box_end.stl]
2014-06-26 Added the ability to power off the strip
    This is done using a 5V relay that cuts the power wire of the strip.
2014-06-26 Updated the schematic to add the relay
    [control.fzz]
2014-07-18 Improved random colors, added rainbow mode
    Random colors are now loaded from the EEPROM, generated first by a
    python script.
    A rainbow mode allows to show changing colors.
    [font.ods]
2014-07-30 Added a version of the grid for laser cutting
    The SVG file is generated by a Python script ensuring accuracy.
2014-08-15 Added the ability to print the frame in one part
    [full_grid.stl, grid.scad, holder.scad]
2014-10-20 Wait for connection if the button is not pushed
    At startup, the button has to be pushed immediately for the demo mode
    to start. Otherwise the frame will wait for the connection forever and
    keep retrying.
2014-11-02 Use Eagle instead of Fritzing for control
    [control.brd, control.fzz, control.sch]
2014-11-02 Made the box bigger for easier Arduino insertion
    [box.scad, box_full.stl]

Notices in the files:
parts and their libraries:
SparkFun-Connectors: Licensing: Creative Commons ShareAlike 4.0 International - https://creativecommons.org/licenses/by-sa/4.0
